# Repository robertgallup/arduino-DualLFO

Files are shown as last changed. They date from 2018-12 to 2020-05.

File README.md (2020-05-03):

# ArduinoDualLFO
---

ArduinoDualLFO uses PWM, interrupts and simple low-pass filters on output pins to create two simultaneous waveforms from an Arduino. The initial design was intended to provide LFO control signals for a musical instrument.

## What's New in V2.0

In V2.0 of ArduinoDualLFO, the LFOs are much more generic and suitable in a wider range of applications.

Changes include:

* Code has been restructured for clarity
* *Settings.h* provides an easy way to control some parameters and compilation options
* A *trigger* input has been added to restart both LFOs at zero
* LFO modes have been removed
* Depth control now has much better resolution
* Improved frequency tracking with the LFO frequency knob

## Description

ArduinoDualLFO assumes that you have certain hardware hooked up to Arduio pins:

* Two potentiometers and a switch for each LFO (frequency, depth, waveform)
* Floating input pin for the trigger input (the default state is determined on startup. Trigger is activated when the state changes)

For more information on the physical connections, see the Fritzing files. I've included the native Fritzing file (Arduino Dual LFO.fzz) as well
as PDF copies the schematic and breadboard layout.

The Arduino sketch is in the Dual_LFO folder. You can copy it to your Arduino Sketches folder. Or,
you can open the sketch directly from the Arduino IDE using File > Open...

Also included is an Excel worksheet that calculates the various waveforms used in the LFOs. Sample data is copied
from the worksheet by selecting the relevant column and copy/pasting it to a sketch header (with variable definition
before and after the data -- see the other wave headers for reference). You can use the worksheet to calculate and add your own waveforms.

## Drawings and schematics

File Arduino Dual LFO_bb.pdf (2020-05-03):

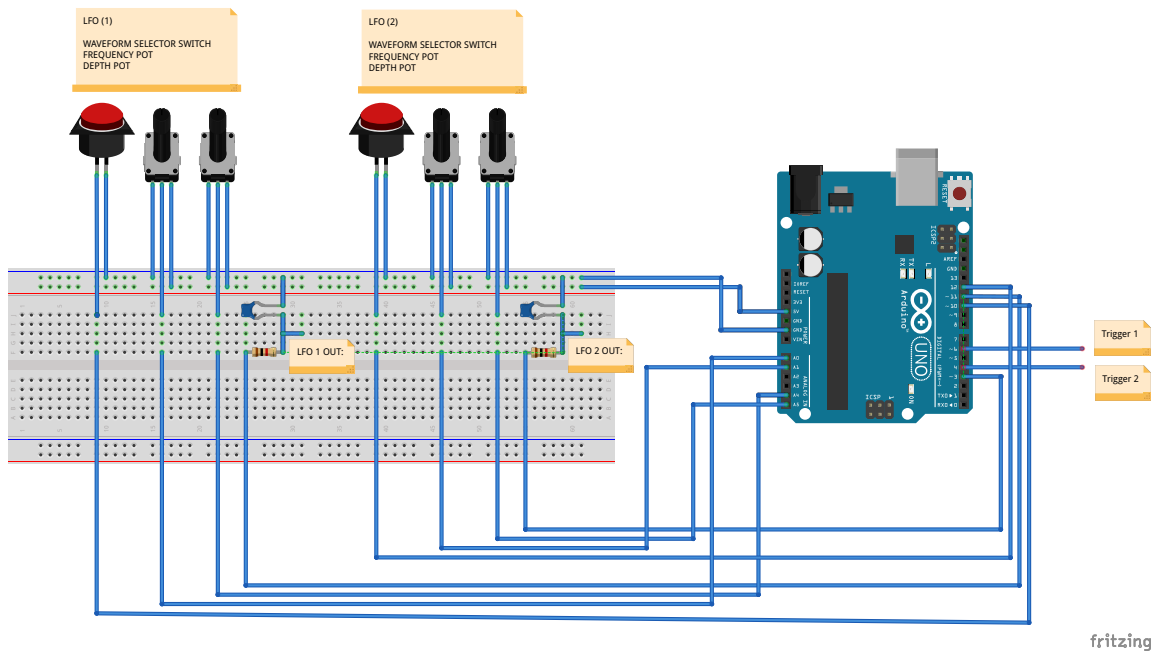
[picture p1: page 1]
Trigger 1; Trigger 2; LFO (2); LFO (1); LFO 1 OUT:; LFO 2 OUT:

WAVEFORM SELECTOR SWITCH
FREQUENCY POT
DEPTH POT

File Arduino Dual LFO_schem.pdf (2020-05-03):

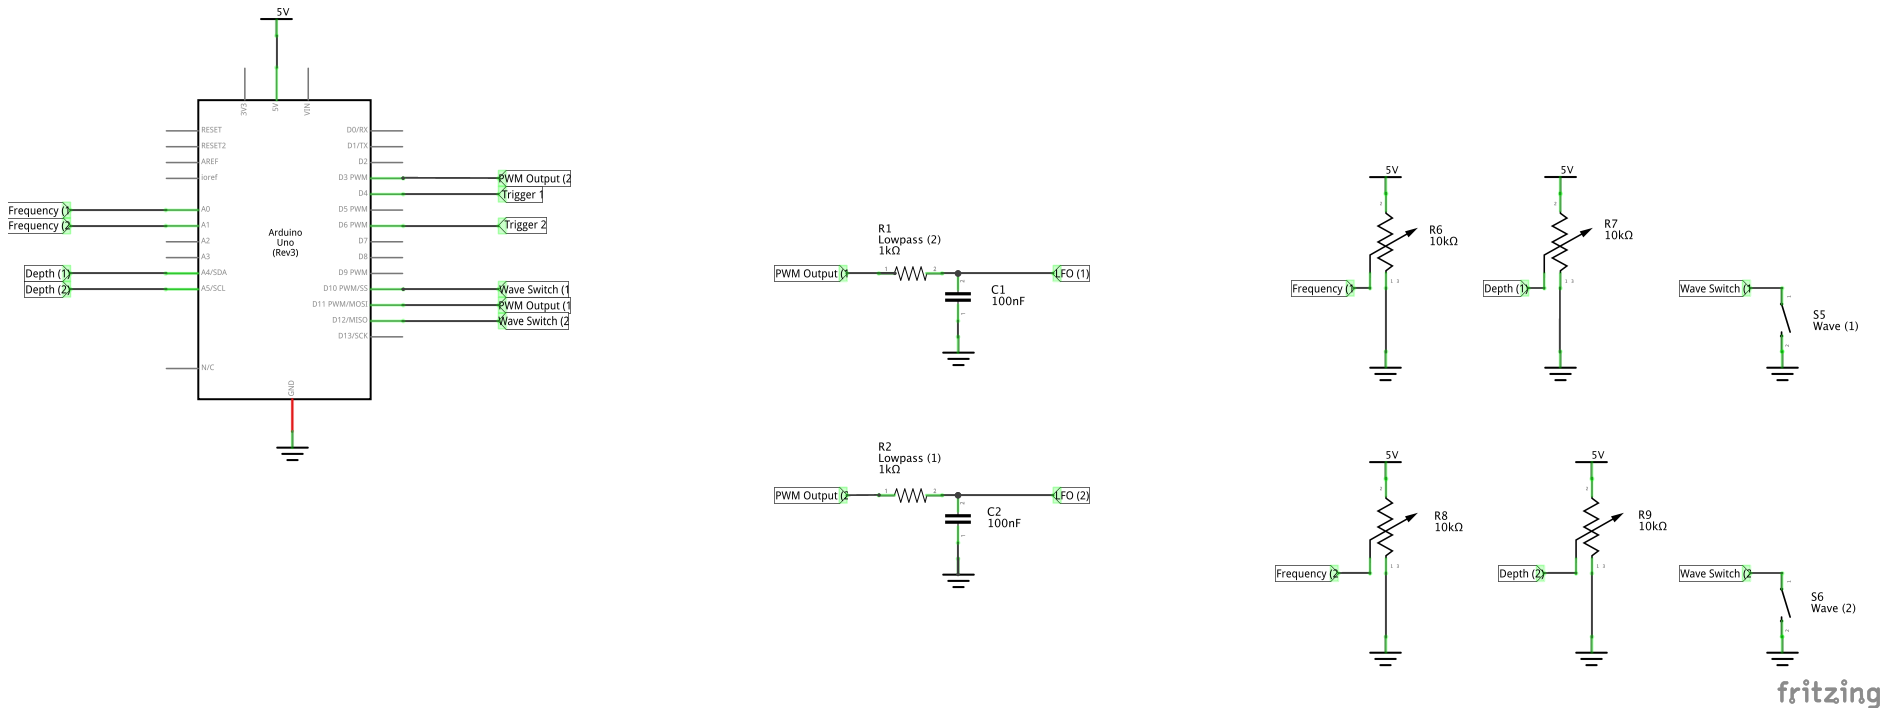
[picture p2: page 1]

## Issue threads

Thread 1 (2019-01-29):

invalid conversion

nicotep, 2019-01-29:
Hi Robert,
When trying to verify your sketch in Arduino i get :
Downloads/ArduinoDualLFO-master/DUAL_LFO/DUAL_LFO.ino:70:98: warning: invalid conversion from 'const byte* {aka const unsigned char*}' to 'byte* {aka unsigned char*}' [-fpermissive]
 byte *waveTables[] = {sine256, ramp256, saw256, tri256, pulse8, pulse16, pulse64, sq256, noise256};

and then later a series of :
/Downloads/ArduinoDualLFO-master/DUAL_LFO/DUAL_LFO.ino:70:98: warning: invalid conversion from 'const byte* {aka const unsigned char*}' to 'byte* {aka unsigned char*}' [-fpermissive]

I suppose it shouldn't compile like this ?
Thanks !

robertgallup, 2019-01-30:
Hi!

I’m not on my computer so can’t check myself, but are you trying to verify Release 1? If so, I believe that version is out of date and does have this error in current Arduino releases.

However, recently I’ve made significant changes that result in more general and useful code. I haven’t had time to create an official Release 2 yet, but if you download the most recent update from GitHub, that might work better. Let me know.

Kind Regards,
Bob

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

robertgallup, 2019-01-30:
BTW, I just made release v2 of the current version (didn’t take too long :) ).

nicotep, 2019-01-31:
Hi Robert, thanks for your answer. The one I was trying to compile is mentionned "2 months ago" so I suppose that was the correct one.
About this v2, where can I find it ? It doesn't appear here in the ArduinoDualLFO github...

robertgallup, 2019-01-31:
OK. I see what's going on. It's a warning, but the code should work. Have you tried running it?

I do have a new version that removes the warning, but I haven't had a chance to test it. I'll try to do that soon and upload it.

BTW, releases are available on the "Code" tab, in the line of links starting "commits branch releases ...". Click on "releases" and you should see them.

robertgallup, 2019-01-31:
I just did a quick test on the update and it seems to be working. So, I created release **v2.0.1**. Let me know if this works.

nicotep, 2019-02-04:
Hi robert,
this last version compiles perfectly. Testing the circuit successfully, nice little configurable LFOs ! Thanks !

Closed 2019-03-28.

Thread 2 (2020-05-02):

Modes cycling

atulrnt, 2020-05-02:
Hi,

I don't see where in the code the mode switch is cycling across the modes.
I actually don't even see the mode switch pin being enabled.

Same thing for the LEDs.

Am I missing something here ?

Thanks a lot for sharing this project anyway, I'm going to give a try !

robertgallup, 2020-05-02:
Hi,

Yes. You’re right. Mode has been removed (and, I should have reflected this in the readme). It was kind of a clumsy implementation to use a single switch to control states of both LFOs. Sorry. :=/

If I can ask, what’s your application?

And, if you have any other questions, let me know…

Bob

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

atulrnt, 2020-05-02:
Thank you for replying so quickly !

So in the v2.0.1, there is actually no way to sync or unsync the LFOs ?
What is the default mode in this version ?

Would you recommend me to make any change on your implementation ?

I'm just starting to build a modular synth with eurorack modules and your dual LFO would be one of those modules.
I'm on a very early stage on both, understanding modular music and building my synth so I'm trying many different things.

robertgallup, 2020-05-02:
Mode is gone, but Sync/trigger is still there and controlled through the settings.h file. By default, the two LFOs have independent sync/trigger inputs (LFO1 on pin 6, LFO2 on pin 4), but they can be mapped to a common pin if you always want to trigger them together (also controlled in settings.h:

Good luck with your modular project. I have plans to build a modular synth myself, but I haven’t made much progress. Maybe one of these days I’ll find the time.  :-)

If you have any more questions, let me know.

Bob

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

atulrnt, 2020-05-02:
Thank you for the clarification !

It took me the whole day (between breadboarding, 3D modelization, 3D printing, painting and assembling) but it' done !

I've added some CV inputs using homemade vactrols to control the depth, I've tried with LFO2 controlling LFO1 and it works great.

FYI, in the schema D3 is the output of LFO1 and D11 is the output of LFO2 but it is the opposite in the code.

Here are some pictures of the module I made.

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

Thank you very much Bob, this is my first module, I'm so happy right now !

Have a great day !

Arthur

robertgallup, 2020-05-03:
Sweet! You work very quickly!

Thanks for pointing out the problem with the schematic. I think I’ve just fixed/updated it.

Some quick questions:

Did you 3D print your faceplate?
How did you make your own vactrol?
Did you add LEDs on the output?
Do you have other modules you’ve created?

Cheers,
Bob

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

robertgallup, 2020-05-03:
BTW, I see you’ve answered all of my questions in your email already (except making your own vactrol). I was too busy looking at the picture to read all the text!

Anyway, excellent job. And, good luck with your next module! :-)

Bob

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

atulrnt, 2020-05-03:
The faceplate is indeed 3D printed using PLA with a thickness of 3.5mm and some reinforcement in some places to avoid it to be too flexible.

The vactrol is simply an LED facing a photo resistor.
I'm using very bright LED which I enclose with the photo resistor in some black heat shrink.
The LED is connected to V+ and Gnd of the CV input (completely isolated from the LFOs circuit) and the photo resistor is connected the Arduino's 5V and the wiper of the pot you want to control.

The LEDs for the output are simply connected between V+ and Gnd of the output with a 1K resistor.

This module is the first module that produces sound, I made an other simple module before which displays the power usage of the +12V, -12V and 5V lines of the synth using an Arduino and 3 INA219.

Thank you again :)

Closed 2020-05-03.

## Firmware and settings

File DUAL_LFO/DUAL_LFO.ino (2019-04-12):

///////////////////////////////////////////////////////////////
//
//  Dual LFO
//
//  For each LFO:
//
//  A momentary switch increments through different wave tables
//  One potentiometer to control LFO frequency
//  One potentiometer to control LFO depth
//  A digital input is used to re-trigger/sync the LFO
//
//  The LFOs output to pins 11 (LFO1) and 3 (LFO2). Since the output is PWM, it's
//  important to add low-pass filters to these pins to smooth out the resulting waveform
//
//  See accompanying Fritzing documents for circuit information.


//  The MIT License (MIT)
//
//  Copyright (c) 2013-2018 Robert W. Gallup (www.robertgallup.com)
//
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

// Macros for clearing and setting bits
#define cbi(sfr, bit) (_SFR_BYTE(sfr) &= ~_BV(bit))
#define sbi(sfr, bit) (_SFR_BYTE(sfr) |= _BV(bit))

// Used in calculating frequency tuning word
// Create constant to to only calculate 2^32 once
const unsigned long long POW2TO32 = pow(2, 32);

// Output Pins (PWM - digital pins)
// WARNING: Don't change these!
const byte LFO1_OUTPUT_PIN = 11;
const byte LFO2_OUTPUT_PIN =  3;

// Control Framework
#include "src/CS_Switch.h"
#include "src/CS_Pot.h"

// Waves
#include "wave/noise256.h"
#include "wave/ramp256.h"
#include "wave/saw256.h"
#include "wave/sine256.h"
#include "wave/tri256.h"
#include "wave/pulse8.h"
#include "wave/pulse16.h"
#include "wave/pulse64.h"
#include "wave/sq256.h"

// Wave table pointers
const byte *waveTables[] = {sine256, ramp256, saw256, tri256, pulse8, pulse16, pulse64, sq256, noise256};

#define NUM_WAVES (sizeof(waveTables) / sizeof(byte *))

// LFO Initial wave table numbers
byte LFO1_WaveTableNum = 0;
byte LFO2_WaveTableNum = 0;

// Optional display
#if defined(DISPLAY)
#include "Display.h"
Display displaySurface;
#endif

#include "Settings.h"

// Calculate LFO frequency ranges
const double LFO1_FREQ_RANGE =    LFO1_FREQ_MAX - LFO1_FREQ_MIN;
const double LFO2_FREQ_RANGE =    LFO2_FREQ_MAX - LFO2_FREQ_MIN;

// Interrupt frequency (16,000,000 / 510)
// 510 is divisor rather than 512 since with phase correct PWM
// an interrupt occurs after one up/down count of the register
// See: https://www.arduino.cc/en/Tutorial/SecretsOfArduinoPWM
const double clock = 31372.549;

// LFO 1 controls
CS_Pot       LFO1_FreqKnob (FREQ1_KNOB_PIN, 3);
CS_Pot       LFO1_DepthKnob (DEPTH1_KNOB_PIN, 3);
CS_Switch    LFO1_WaveSwitch(WAVE1_SWITCH_PIN);

// LFO 2 controls
CS_Pot       LFO2_FreqKnob (FREQ2_KNOB_PIN, 3);
CS_Pot       LFO2_DepthKnob (DEPTH2_KNOB_PIN, 3);
CS_Switch    LFO2_WaveSwitch (WAVE2_SWITCH_PIN);

// Generic pin state variable
byte pinState;

// SYNC variables defined for optional SYNC feature, if defined in Settings.h
#if defined(SYNC)
byte lastSYNC1;
#if !defined(SYNC_COMMON)
byte lastSYNC2;
#endif
#endif

// Interrupt variables are volatile
volatile byte tickCounter;               // Counts interrupt "ticks". Reset every 125
volatile byte fourMilliCounter;          // Counter incremented every 4ms

volatile unsigned long accumulatorA;     // Accumulator LFO1
volatile unsigned long LFO1_TuningWord;  // DDS tuning
volatile unsigned long LFO1_Depth;       // CV depth

volatile unsigned long accumulatorB;     // Accumulator LFO2
volatile unsigned long LFO2_TuningWord;  // DDS tuning
volatile unsigned long LFO2_Depth;       // CV depth

volatile byte *LFO1_WaveTable;
volatile byte *LFO2_WaveTable;

void setup()
{

#if defined(SYNC)
  // Initialize SYNC pin(s) for optional SYNC feature in Settings.h
  pinMode(SYNC1_PIN, INPUT);
  lastSYNC1 = (HIGH == SYNC1_TRIGGER) ? LOW : HIGH;
#if !defined(SYNC_COMMON)
  pinMode(SYNC2_PIN, INPUT);
  lastSYNC2 = (HIGH == SYNC2_TRIGGER) ? LOW : HIGH;
#endif
#endif

#if defined(DISPLAY)
  // Initialize display
  displaySurface.begin();
#endif

  // Initialize PWM Pins
  pinMode(LFO1_OUTPUT_PIN, OUTPUT);     // pin11= PWM:A
  pinMode(LFO2_OUTPUT_PIN, OUTPUT);     // pin 3= PWM:B

  // Initialize knobs
  LFO1_FreqKnob.begin();
  LFO1_DepthKnob.begin();
  LFO2_FreqKnob.begin();
  LFO2_DepthKnob.begin();


  // Initialize wave tables
  LFO1_WaveTable = (byte*)waveTables[0];
  LFO2_WaveTable = (byte*)waveTables[0];

  // Initialize wave switch states
  while (LFO1_WaveSwitch.stateDebounced() == 0);
  while (LFO2_WaveSwitch.stateDebounced() == 0);

  // Initialize timer
  Setup_timer2();

}


void loop()
{

  // SYNC code included if SYNC option defined in Settings.h
#if defined(SYNC)

  // SYNC 1 + SYNC_COMMON
  pinState = digitalRead(SYNC1_PIN);
  if (pinState != lastSYNC1) {
    lastSYNC1 = pinState;
    if (pinState == SYNC1_TRIGGER) {
      accumulatorA = 0;
#if defined(SYNC_COMMON)
      accumulatorB = 0;
#endif
    }
  }

  // Separate SYNC inputs processed if SYNC1 and SYNC2 pins are different
#if !defined(SYNC_COMMON)
  // SYNC 2 (SYNC pins are separate)
  pinState = digitalRead(SYNC2_PIN);
  if (pinState != lastSYNC2) {
    lastSYNC2 = pinState;
    if (pinState == SYNC2_TRIGGER) accumulatorB = 0;
  }
#endif

#endif

  // Check controls every 1/10 second
  if (fourMilliCounter > 25) {
    fourMilliCounter = 0;

    // If DISPLAY defined in Settings.h
#if defined(DISPLAY)
    displaySurface.update();
#endif

    // LFO 1 wave table switch
    pinState = LFO1_WaveSwitch.stateDebounced();
    if (LFO1_WaveSwitch.changed()) {
      if (pinState == 1) {
        LFO1_WaveTableNum = (LFO1_WaveTableNum + 1) % NUM_WAVES;
        LFO1_WaveTable = (byte*)waveTables[LFO1_WaveTableNum];
      }
    }

    // LFO 2 wave table switch
    pinState = LFO2_WaveSwitch.stateDebounced();
    if (LFO2_WaveSwitch.changed()) {
      if (pinState == 1) {
        LFO2_WaveTableNum = (LFO2_WaveTableNum + 1) % NUM_WAVES;
        LFO2_WaveTable = (byte*)waveTables[LFO2_WaveTableNum];
      }
    }

    // LFO 1 frequency/depth controls
    LFO1_TuningWord = POW2TO32 * (((((double)LFO1_FreqKnob.value() * LFO1_FREQ_RANGE) / 1024L) + LFO1_FREQ_MIN) / clock);
    LFO1_Depth  = LFO1_DepthKnob.value();

    // LFO 2 frequency/depth controls
    LFO2_TuningWord = POW2TO32 * (((((double)LFO2_FreqKnob.value() * LFO2_FREQ_RANGE) / 1024L) + LFO2_FREQ_MIN) / clock);
    LFO2_Depth  = LFO2_DepthKnob.value();
  }

}

//******************************************************************
// timer2 setup
//
void Setup_timer2() {

  // Prescaler 1
  sbi (TCCR2B, CS20);
  cbi (TCCR2B, CS21);
  cbi (TCCR2B, CS22);

  // Non-inverted PWM
  cbi (TCCR2A, COM2A0);
  sbi (TCCR2A, COM2A1);
  cbi (TCCR2A, COM2B0);
  sbi (TCCR2A, COM2B1);

  // Phase Correct PWM
  sbi (TCCR2A, WGM20);
  cbi (TCCR2A, WGM21);
  cbi (TCCR2B, WGM22);

  // Enable interrupt
  sbi (TIMSK2, TOIE2);

}

////////////////////////////////////////////////////////////////
//
// Timer2 Interrupt Service
// Frequency = 16,000,000 / 510 = 31372.5
//
ISR(TIMER2_OVF_vect) {

  byte offset;

  // Count every four milliseconds
  if (tickCounter++ == 125) {
    fourMilliCounter++;
    tickCounter = 0;
  }

  // Sample wave table for LFO1
  accumulatorA  += LFO1_TuningWord;
  offset         = accumulatorA >> 24; // high order byte
  OCR2A          = (pgm_read_byte_near(LFO1_WaveTable + offset) * LFO1_Depth) / 1024L;

  // Sample wave table for LFO2
  accumulatorB  += LFO2_TuningWord;
  offset         = accumulatorB >> 24; // high order byte
  OCR2B          = (pgm_read_byte_near(LFO2_WaveTable + offset) * LFO2_Depth) / 1024L;

}

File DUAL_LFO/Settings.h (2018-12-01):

// Settings 

// Comment out the following #define to deactivate SYNC input(s)
// Specify whether HIGH or LOW is the trigger state using "TRIGGER" constants
// To use a common pin for syncing both LFOs, define SYNC_COMMON (uncomment the #define)
// The common pin/trigger are taken from SYNC1

#define SYNC
#if defined(SYNC)
//#define SYNC_COMMON
const byte SYNC1_PIN =            6;
const byte SYNC1_TRIGGER =        HIGH;
const byte SYNC2_PIN =            4;
const byte SYNC2_TRIGGER =        HIGH;
#endif

// Uncomment this to initialize and update a user-supplied display
//#define DISPLAY

// KNOBS (analog pins)

const byte FREQ1_KNOB_PIN =         0;
const byte DEPTH1_KNOB_PIN =        4;

const byte FREQ2_KNOB_PIN =         1;
const byte DEPTH2_KNOB_PIN =        5;

// SWITCHES (digital pins)

const byte WAVE1_SWITCH_PIN =      10;
const byte WAVE2_SWITCH_PIN =      12;

// LFO SETTINGS
const double LFO1_FREQ_MIN =      0.1;
const double LFO1_FREQ_MAX =      100;

const double LFO2_FREQ_MIN =      0.1;
const double LFO2_FREQ_MAX =      100;

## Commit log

2013-06-22 Version 1.0
    [Arduino Dual LFO.fzz]
2013-06-30 Added pulse waveforms and Excel worksheet for calculating waveforms (see readme for more info)
    [256ByteWaveforms.xlsx]
2015-06-14 Added gitignore and updated Fritzing drawing
    [Arduino Dual LFO.fzz]
2018-11-24 Many changes/improvements to make this a general purpose dual oscillator.
    [CS_Switch.cpp, DUAL_LFO.ino, Settings.h]
2018-11-24 Changes to readme and frequency tracking.
    [Arduino Dual LFO.fzz]
2018-11-28 Fixed triggering on separate pins.
    [DUAL_LFO.ino, Settings.h]
2018-11-30 Fixed oscillator range calculation
    [DUAL_LFO.ino, Settings.h]
2018-12-05 Smoothed pot values to reduce jitter
    [DUAL_LFO.ino]
2019-01-31 Fixed casting issue related to const pointers to wavetables
    [DUAL_LFO.ino]
2020-05-02 Remove Mode from readme, update diagrams
    Updates to remove Mode documentation and update diagrams
    [Arduino Dual LFO.fzz]
2020-05-03 Corrected LFO output connections in schematic
    [Arduino Dual LFO.fzz]
